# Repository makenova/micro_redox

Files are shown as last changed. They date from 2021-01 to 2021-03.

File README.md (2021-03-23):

# micro_redox

A family of 40% choc keyboards(34 keys) inspired by the Microdox and Ferris keyboards. 

 - The **micro_redox_split** is a pro-micro powered reversible split that does not require diodes.
 - The **micro_redox_semi_spit** is an integrated mcu semi split with usb-c and a rotary encoder.

Both boards can use either hot-swap sockets or the switches can be soldered directly to the pcb.

## Inspiration and differences

The Microdox(36 key MX spaced split) from Boardsource is a great keyboard. It was my first choc board, and after trying out a few keymaps, I realized I didn't need the outer thumb keys. In my experience, those keys are difficult to reach and do not serve a purpose on the keymap I've settled on.   
The Ferris(34 key choc spaced split) is another great keyboard. I like the look of the Ferris but a couple things made it uncomfortable for me to use:

* the thumb cluster is too close to the alphas 
* the pinky stagger is aggressive 

For the micro_redox family, I have kept the column stagger from the Microdox, made it choc spaced, and removed the outter thumb keys. I have also kept the distance between the homing keys and the thumb keys because I find it comfortable. Finally, I rotated the innermost thumb key which means that only 1u keycaps will fit there.  
For the split, I've also used a reversible pro-micro footprint so that both of them can face the same way i.e. component side down. It's a cleaner look.

## Libraries

These libraries that help me move fast. I may not actually be using them in this project, but adding them to keyboard projects is a habit. The are all added as git submodules so make sure you pull them down after you pull the repo.  
My thanks to the authors for sharing.

- [Keebio-components](https://github.com/keebio/keebio-components)
  - [@keebio](https://github.com/keebio)
- [Keebio-parts.pretty](https://github.com/keebio/Keebio-Parts.pretty)
  - [@keebio](https://github.com/keebio)
- [keyswtiches.pretty](https://github.com/daprice/keyswitches.pretty)
  - [@daprice](https://github.com/daprice)
- [random-keyboard-parts.pretty](https://github.com/ai03-2725/random-keyboard-parts.pretty)
  - [@ai03-2725](https://github.com/ai03-2725)
- [https://github.com/foostan/kbd](https://github.com/foostan/kbd)
  - [@foostan](https://github.com/foostan)
- [Customizable Rotary Encoder Knob](https://www.thingiverse.com/thing:2797118)
  - [tsw](https://www.thingiverse.com/tsw/designs)

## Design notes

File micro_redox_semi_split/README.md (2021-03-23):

# micro_redox_semi_split
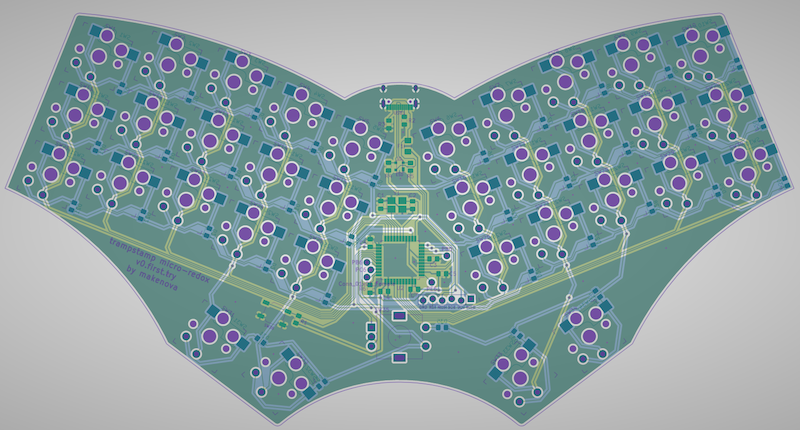
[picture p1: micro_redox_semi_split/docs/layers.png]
layers


### Features

- USB C
- integrated mcu
- rotary encoder
- choc spaced
- hot-swap or soldered

There are production files in the "gerbers" directory for the pcb and a skeleton case.
Simply upload the zip files to your PCB manufacturer of choice.

If you do not get this assembled by a factory you can find an interactive BOM in `bom` directory.

Starting firmware can be found on my QMK fork in the [`makenova`](https://github.com/makenova/qmk_firmware/tree/makenova/keyboards/makenova//micro_redox/semi_split) branch.

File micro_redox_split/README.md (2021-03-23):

# micro_redox_split
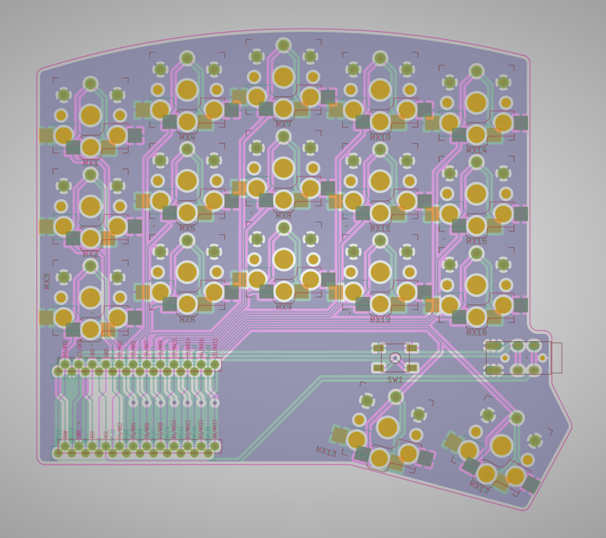
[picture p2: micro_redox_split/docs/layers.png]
layers


### Features

- diodeless
- reversible pcb
- reversible mcu
- choc spaced
- hot-swap or soldered

There are production files in the "gerbers" directory for the pcb and a skeleton case.
Just upload the zip files to your PCB manufacturer of choice.

You'll also need

* Pro Micro(PM) or compatible board
 * I prefer something with USB C
 * You can use a nice!nano if you want to make it wireless
* Headers for the PM
  * search for `Round Female Socket Pin Header`
* TRRS jack
* choc hot-swap sockets(optional)
* reset switch (optional)

Starting firmware can be found on my QMK fork in the [`makenova`](https://github.com/makenova/qmk_firmware/tree/makenova/keyboards/makenova//micro_redox/split) branch.

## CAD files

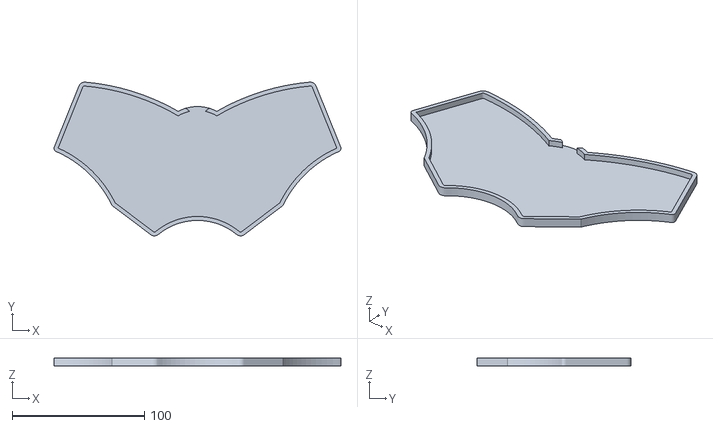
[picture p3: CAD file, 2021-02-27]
micro_redox_semi_split/docs/semi_split_slip_on.stl
217.1 x 116.3 x 6.00

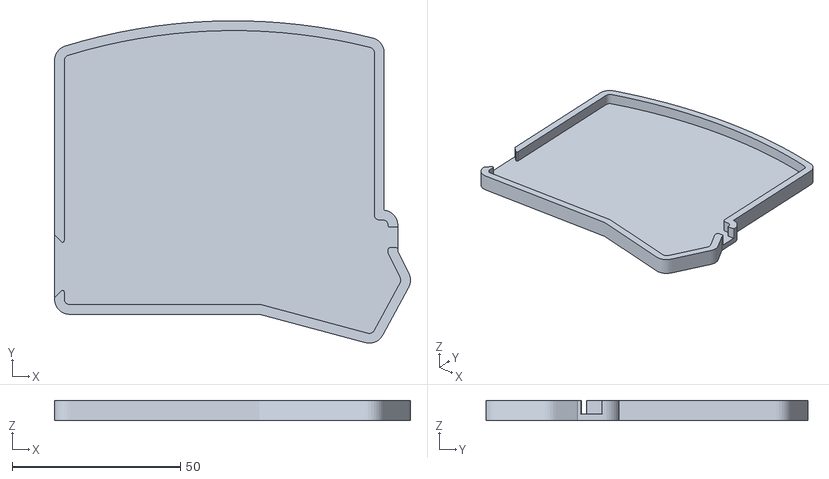
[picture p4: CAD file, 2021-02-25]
micro_redox_split/docs/slip-on.stl
105.9 x 95.9 x 6.00

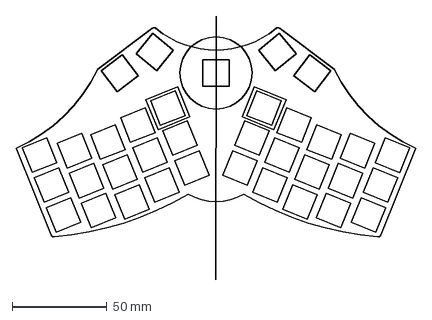
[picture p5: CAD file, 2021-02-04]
micro_redox_semi_split/docs/semi_split_plate_1_0.dxf
210.6 x 139.0 mm

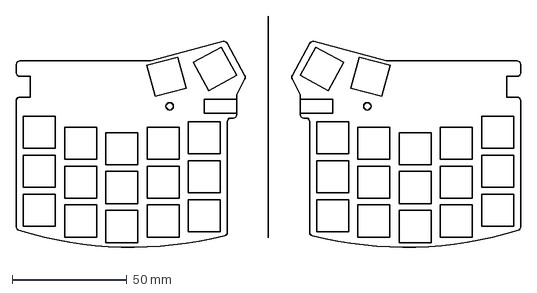
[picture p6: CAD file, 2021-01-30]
micro_redox_split/docs/plate_1_0.dxf
220.0 x 103.1 mm

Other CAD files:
HRO__TYPE-C-31-M-12.f3d

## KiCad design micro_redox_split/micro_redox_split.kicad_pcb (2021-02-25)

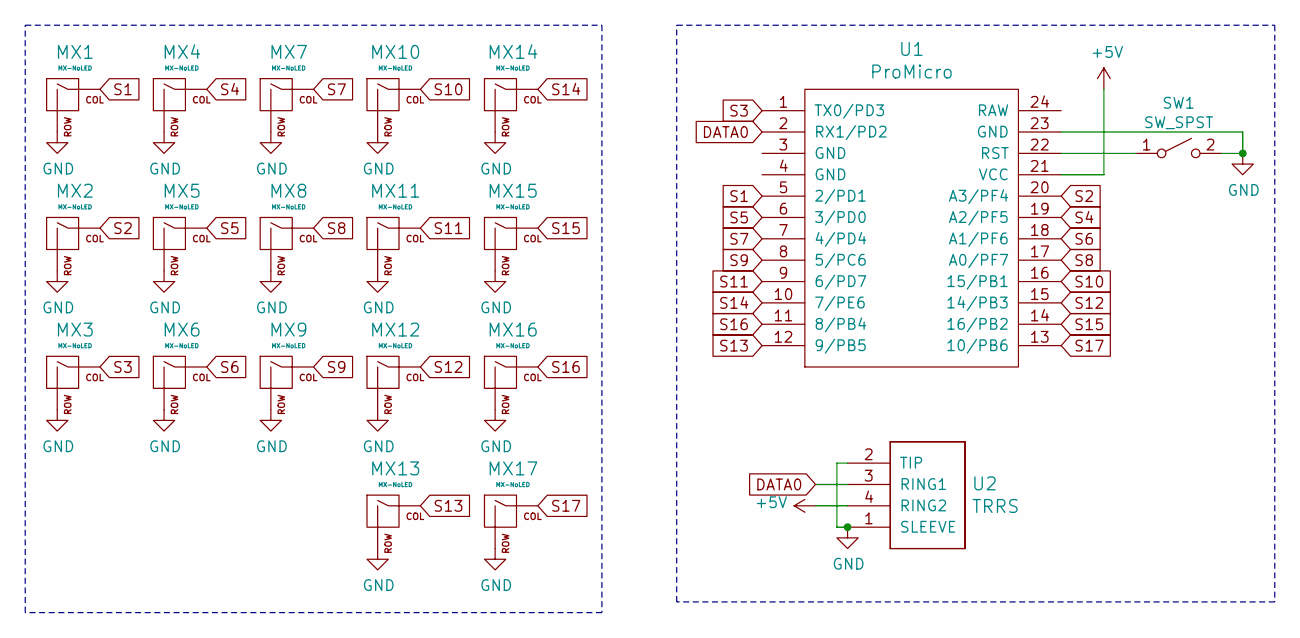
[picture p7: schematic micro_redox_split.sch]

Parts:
MX1, MX2, MX3, MX4, MX5, MX6, MX7, MX8, MX9, MX10, MX11, MX12, MX13, MX14, MX15, MX16, MX17: MX-NoLED; Kailh_socket_PG1350_optional_reversible
SW1: SW_SPST; SKQG-1155865-makenova-reversible
U1: ProMicro; ProMicro_v2-makenova-micro-redox
U2: TRRS; TRRS-PJ-320A-no-Fmask-makenova-reversible

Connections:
+5V: U1.21 (VCC), U2.4 (RING2)
DATA0: U1.2 (RX1/PD2), U2.3 (RING1)
GND: MX1.2 (ROW), MX2.2 (ROW), MX3.2 (ROW), MX4.2 (ROW), MX5.2 (ROW), MX6.2 (ROW), MX7.2 (ROW), MX8.2 (ROW), MX9.2 (ROW), MX10.2 (ROW), MX11.2 (ROW), MX12.2 (ROW), MX13.2 (ROW), MX14.2 (ROW), MX15.2 (ROW), MX16.2 (ROW), MX17.2 (ROW), SW1.2 (B), U1.23 (GND), U2.1 (SLEEVE), U2.2 (TIP)
unnamed: SW1.1 (A), U1.22 (RST)
S1: MX1.1 (COL), U1.5 (2/PD1)
S2: MX2.1 (COL), U1.20 (A3/PF4)
S3: MX3.1 (COL), U1.1 (TX0/PD3)
S4: MX4.1 (COL), U1.19 (A2/PF5)
S5: MX5.1 (COL), U1.6 (3/PD0)
S6: MX6.1 (COL), U1.18 (A1/PF6)
S7: MX7.1 (COL), U1.7 (4/PD4)
S8: MX8.1 (COL), U1.17 (A0/PF7)
S9: MX9.1 (COL), U1.8 (5/PC6)
S10: MX10.1 (COL), U1.16 (15/PB1)
S11: MX11.1 (COL), U1.9 (6/PD7)
S12: MX12.1 (COL), U1.15 (14/PB3)
S13: MX13.1 (COL), U1.12 (9/PB5)
S14: MX14.1 (COL), U1.10 (7/PE6)
S15: MX15.1 (COL), U1.14 (16/PB2)
S16: MX16.1 (COL), U1.11 (8/PB4)
S17: MX17.1 (COL), U1.13 (10/PB6)

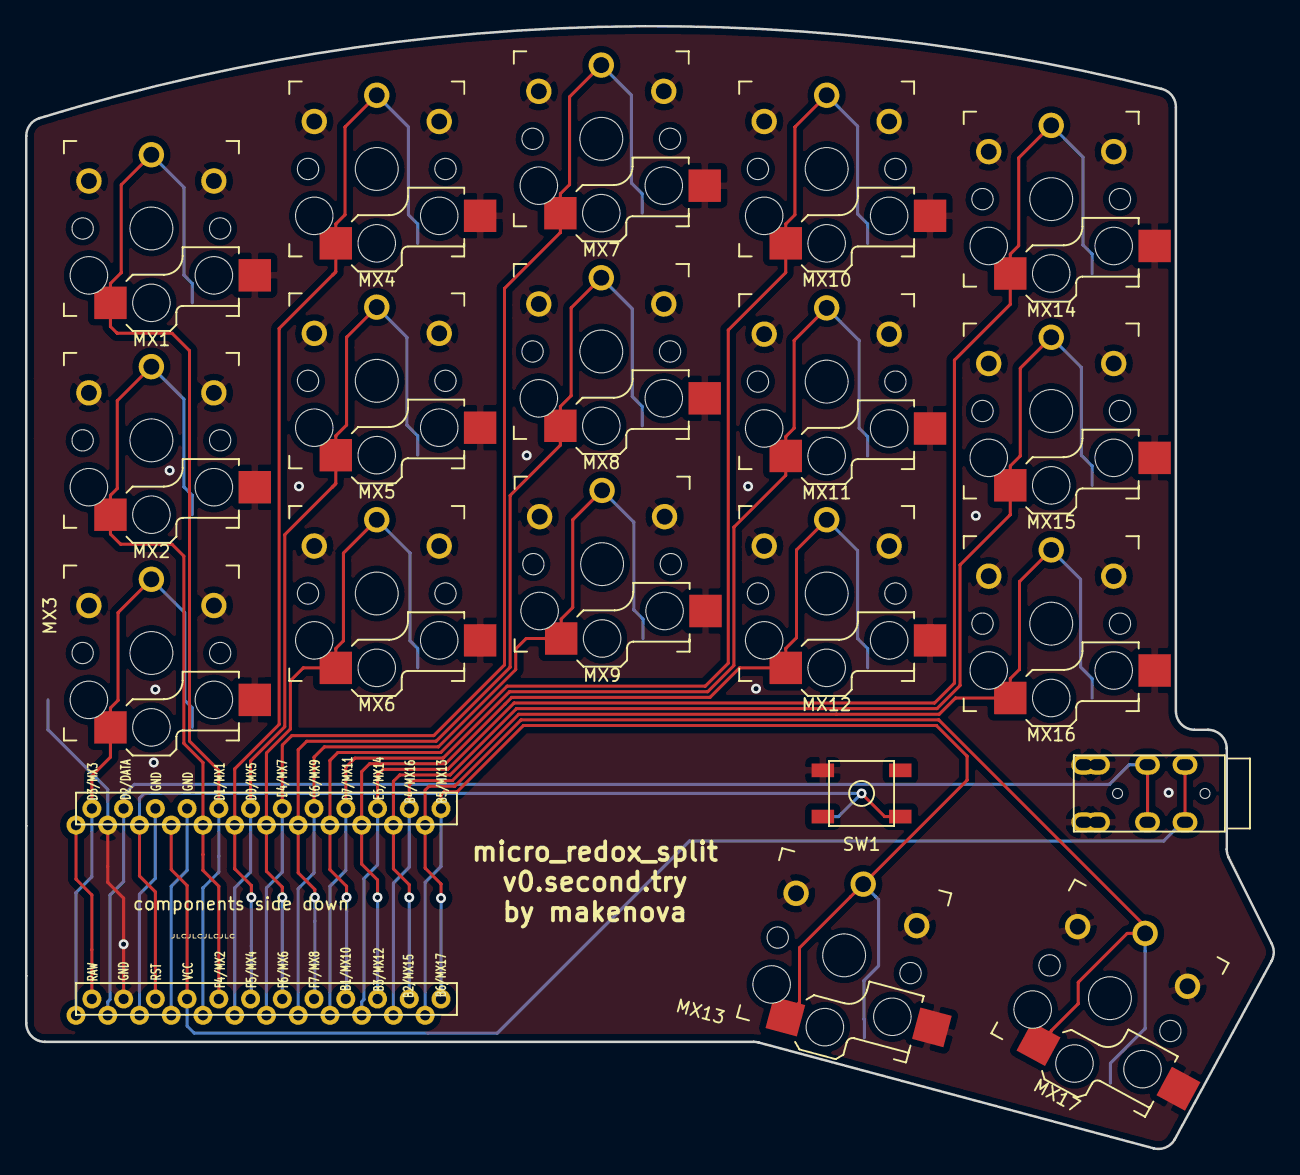
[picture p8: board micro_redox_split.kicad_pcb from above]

Board: 2 copper layers, 99.8 x 89.8 mm, 20 parts (1 on the bottom side), 21 nets.

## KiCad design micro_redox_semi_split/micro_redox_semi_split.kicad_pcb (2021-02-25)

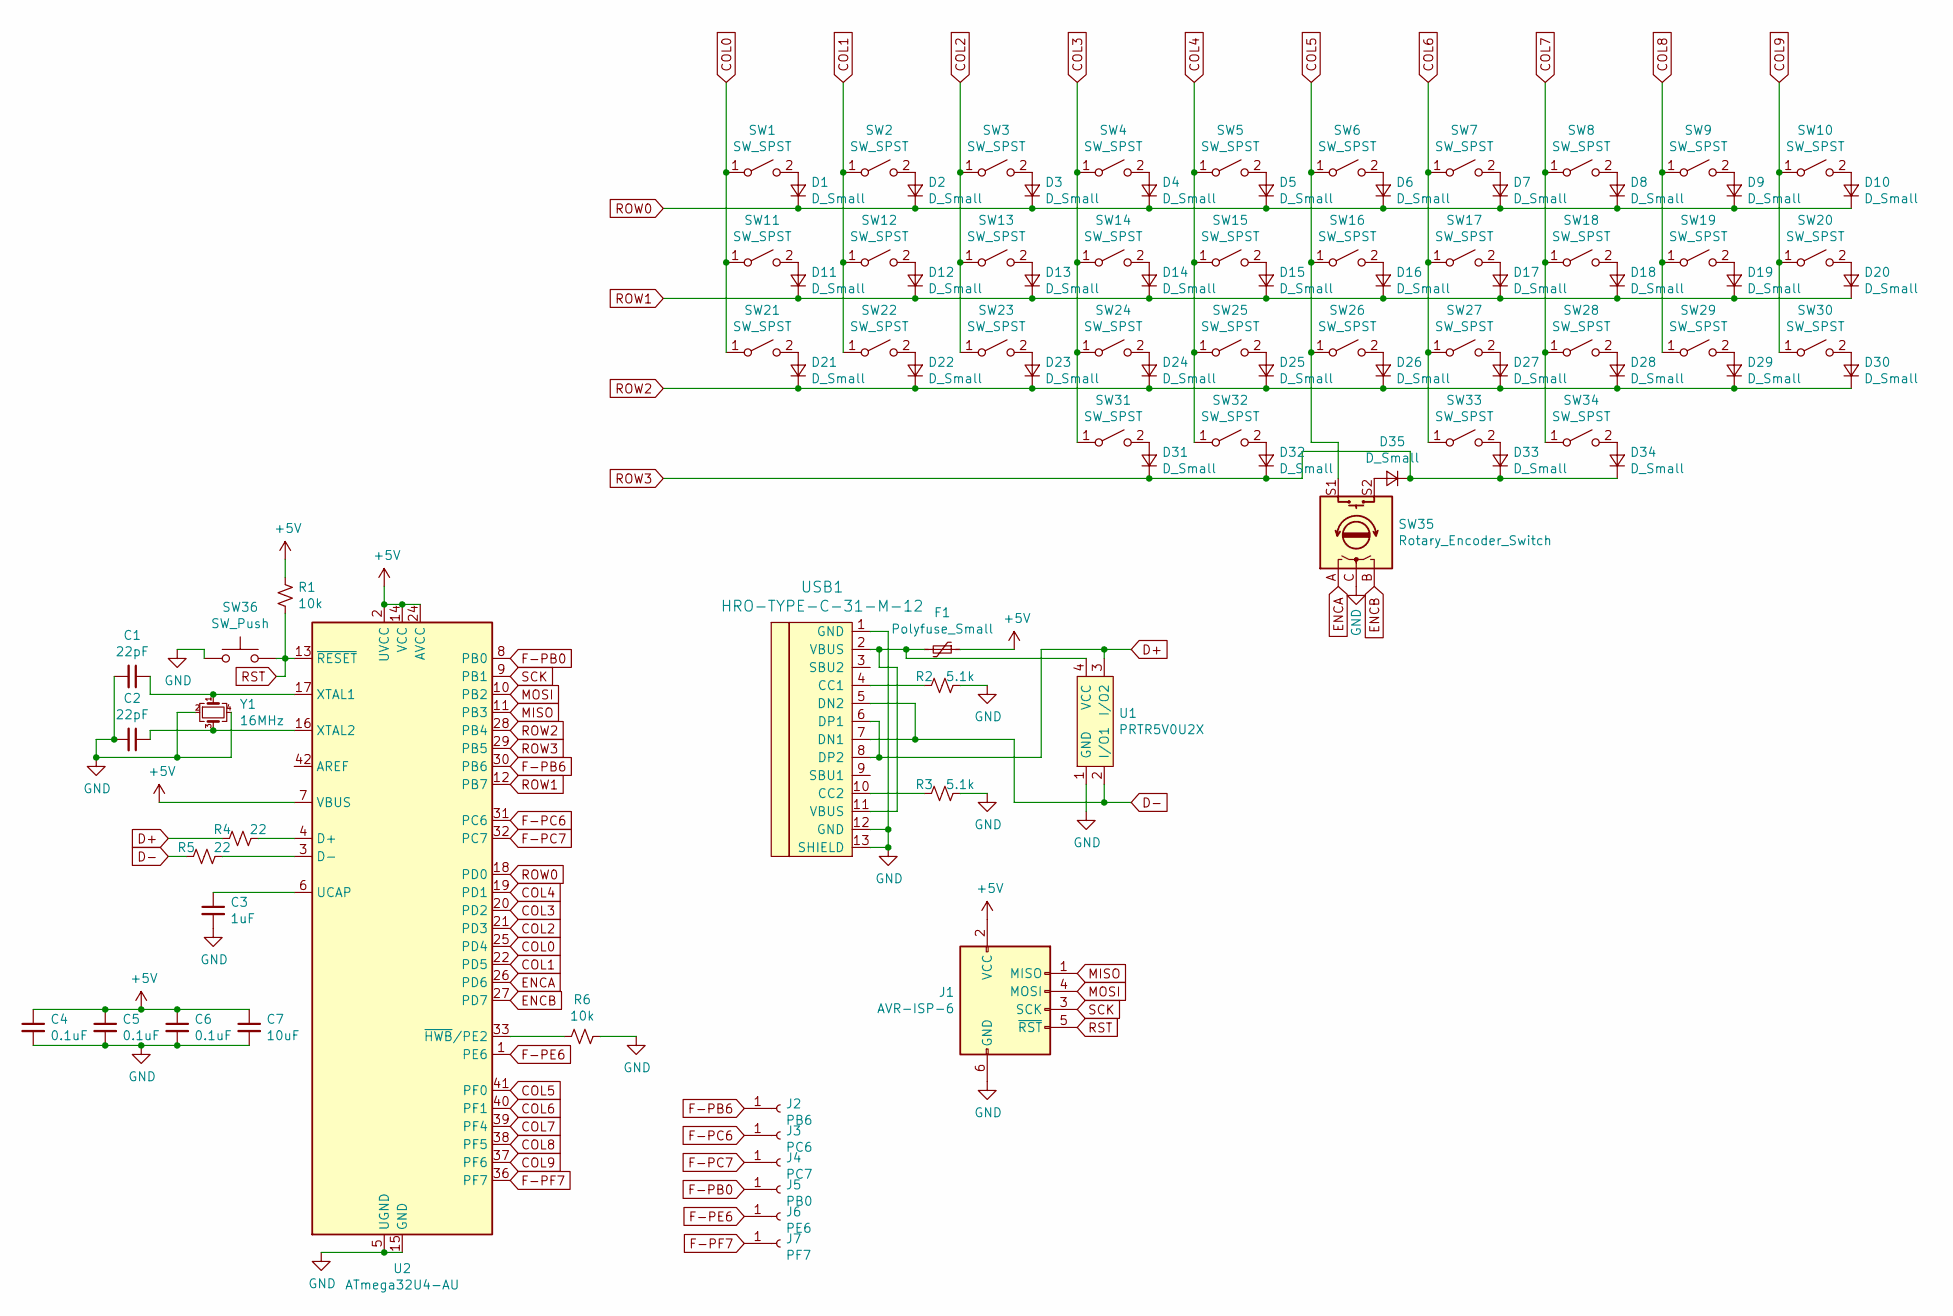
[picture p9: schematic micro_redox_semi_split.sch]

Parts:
C1, C2: 22pF; C_0805_2012Metric_Pad1.15x1.40mm_HandSolder
C3: 1uF; C_0805_2012Metric_Pad1.15x1.40mm_HandSolder
C4, C5, C6: 0.1uF; C_0805_2012Metric_Pad1.15x1.40mm_HandSolder
C7: 10uF; C_0805_2012Metric_Pad1.15x1.40mm_HandSolder
D1, D2, D3, D4, D5, D6, D7, D8, D9, D10, D11, D12, D13, D14, D15, D16, D17, D18, D19, D20, D21, D22, D23, D24, D25, D26, D27, D28, D29, D30, D31, D32, D33, D34, D35: D_Small; D_SOD-123
F1: Polyfuse_Small; Fuse_1206_3216Metric_Pad1.42x1.75mm_HandSolder
J1: AVR-ISP-6; ICSP-Header-ZigZag
J2: PB6; SinglePad
J3: PC6; SinglePad
J4: PC7; SinglePad
J5: PB0; SinglePad
J6: PE6; SinglePad
J7: PF7; SinglePad
R1, R6: 10k; R_0805_2012Metric_Pad1.15x1.40mm_HandSolder
R2, R3: 5.1k; R_0805_2012Metric_Pad1.15x1.40mm_HandSolder
R4, R5: 22; R_0805_2012Metric_Pad1.15x1.40mm_HandSolder
SW1, SW2, SW3, SW4, SW5, SW6, SW7, SW8, SW9, SW10, SW11, SW12, SW13, SW14, SW15, SW16, SW17, SW18, SW19, SW20, SW21, SW22, SW23, SW24, SW25, SW26, SW27, SW28, SW29, SW30, SW31, SW32, SW33, SW34: SW_SPST; Kailh_socket_PG1350_optional
SW35: Rotary_Encoder_Switch; RotaryEncoder_Alps_EC11E-Switch_Vertical_H20mm
SW36: SW_Push; SW_SPST_TL3342
U1: PRTR5V0U2X; SOT-143B
U2: ATmega32U4-AU; TQFP-44_10x10mm_P0.8mm
USB1: HRO-TYPE-C-31-M-12; HRO-TYPE-C-31-M-12-Assembly
Y1: 16MHz; Crystal_SMD_3225-4Pin_3.2x2.5mm_HandSoldering

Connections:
+5V: C4.1, C5.1, C6.1, C7.1, F1.1, J1.2 (VCC), R1.2, U2.2 (UVCC), U2.7 (VBUS), U2.14 (VCC), U2.24 (AVCC), U2.34 (VCC), U2.44 (AVCC)
COL0: SW1.1 (A), SW11.1 (A), SW21.1 (A), U2.25 (PD4)
COL1: SW2.1 (A), SW12.1 (A), SW22.1 (A), U2.22 (PD5)
COL2: SW3.1 (A), SW13.1 (A), SW23.1 (A), U2.21 (PD3)
COL3: SW4.1 (A), SW14.1 (A), SW24.1 (A), SW31.1 (A), U2.20 (PD2)
COL4: SW5.1 (A), SW15.1 (A), SW25.1 (A), SW32.1 (A), U2.19 (PD1)
COL5: SW6.1 (A), SW16.1 (A), SW26.1 (A), SW35.S1, U2.41 (PF0)
COL6: SW7.1 (A), SW17.1 (A), SW27.1 (A), SW33.1 (A), U2.40 (PF1)
COL7: SW8.1 (A), SW18.1 (A), SW28.1 (A), SW34.1 (A), U2.39 (PF4)
COL8: SW9.1 (A), SW19.1 (A), SW29.1 (A), U2.38 (PF5)
COL9: SW10.1 (A), SW20.1 (A), SW30.1 (A), U2.37 (PF6)
D+: R4.2, U1.3 (I/O2), USB1.6 (DP1), USB1.8 (DP2)
D-: R5.1, U1.2 (I/O1), USB1.5 (DN2), USB1.7 (DN1)
ENCA: SW35.A, U2.26 (PD6)
ENCB: SW35.B, U2.27 (PD7)
F-PB0: J5.1, U2.8 (PB0)
F-PB6: J2.1, U2.30 (PB6)
F-PC6: J3.1, U2.31 (PC6)
F-PC7: J4.1, U2.32 (PC7)
F-PE6: J6.1, U2.1 (PE6)
F-PF7: J7.1, U2.36 (PF7)
GND: C1.2, C2.2, C3.2, C4.2, C5.2, C6.2, C7.2, J1.6 (GND), R2.1, R3.1, R6.1, SW35.C, SW36.1, U1.1 (GND), U2.5 (UGND), U2.15 (GND), U2.23 (GND), U2.35 (GND), U2.43 (GND), USB1.1 (GND), USB1.12 (GND), USB1.13 (SHIELD), Y1.2, Y1.4
MISO: J1.1 (MISO), U2.11 (PB3)
MOSI: J1.4 (MOSI), U2.10 (PB2)
unnamed: C1.1, U2.17 (XTAL1), Y1.1
unnamed: C2.1, U2.16 (XTAL2), Y1.3
unnamed: C3.1, U2.6 (UCAP)
unnamed: D1.2 (A), SW1.2 (B)
unnamed: D2.2 (A), SW2.2 (B)
unnamed: D3.2 (A), SW3.2 (B)
unnamed: D4.2 (A), SW4.2 (B)
unnamed: D5.2 (A), SW5.2 (B)
unnamed: D6.2 (A), SW6.2 (B)
unnamed: D7.2 (A), SW7.2 (B)
unnamed: D8.2 (A), SW8.2 (B)
unnamed: D9.2 (A), SW9.2 (B)
unnamed: D10.2 (A), SW10.2 (B)
unnamed: D11.2 (A), SW11.2 (B)
unnamed: D12.2 (A), SW12.2 (B)
unnamed: D13.2 (A), SW13.2 (B)
unnamed: D14.2 (A), SW14.2 (B)
unnamed: D15.2 (A), SW15.2 (B)
unnamed: D16.2 (A), SW16.2 (B)
unnamed: D17.2 (A), SW17.2 (B)
unnamed: D18.2 (A), SW18.2 (B)
unnamed: D19.2 (A), SW19.2 (B)
unnamed: D20.2 (A), SW20.2 (B)
unnamed: D21.2 (A), SW21.2 (B)
unnamed: D22.2 (A), SW22.2 (B)
unnamed: D23.2 (A), SW23.2 (B)
unnamed: D24.2 (A), SW24.2 (B)
unnamed: D25.2 (A), SW25.2 (B)
unnamed: D26.2 (A), SW26.2 (B)
unnamed: D27.2 (A), SW27.2 (B)
unnamed: D28.2 (A), SW28.2 (B)
unnamed: D29.2 (A), SW29.2 (B)
unnamed: D30.2 (A), SW30.2 (B)
unnamed: D31.2 (A), SW31.2 (B)
unnamed: D32.2 (A), SW32.2 (B)
unnamed: D33.2 (A), SW33.2 (B)
unnamed: D34.2 (A), SW34.2 (B)
unnamed: D35.2 (A), SW35.S2
unnamed: F1.2, U1.4 (VCC), USB1.2 (VBUS), USB1.11 (VBUS)
unnamed: R2.2, USB1.4 (CC1)
unnamed: R3.2, USB1.10 (CC2)
unnamed: R4.1, U2.4 (D+)
unnamed: R5.2, U2.3 (D-)
unnamed: R6.2, U2.33 (~HWB~/PE2)
ROW0: D1.1 (K), D2.1 (K), D3.1 (K), D4.1 (K), D5.1 (K), D6.1 (K), D7.1 (K), D8.1 (K), D9.1 (K), D10.1 (K), U2.18 (PD0)
ROW1: D11.1 (K), D12.1 (K), D13.1 (K), D14.1 (K), D15.1 (K), D16.1 (K), D17.1 (K), D18.1 (K), D19.1 (K), D20.1 (K), U2.12 (PB7)
ROW2: D21.1 (K), D22.1 (K), D23.1 (K), D24.1 (K), D25.1 (K), D26.1 (K), D27.1 (K), D28.1 (K), D29.1 (K), D30.1 (K), U2.28 (PB4)
ROW3: D31.1 (K), D32.1 (K), D33.1 (K), D34.1 (K), D35.1 (K), U2.29 (PB5)
RST: J1.5 (~RST), R1.1, SW36.2, U2.13 (~RESET)
SCK: J1.3 (SCK), U2.9 (PB1)

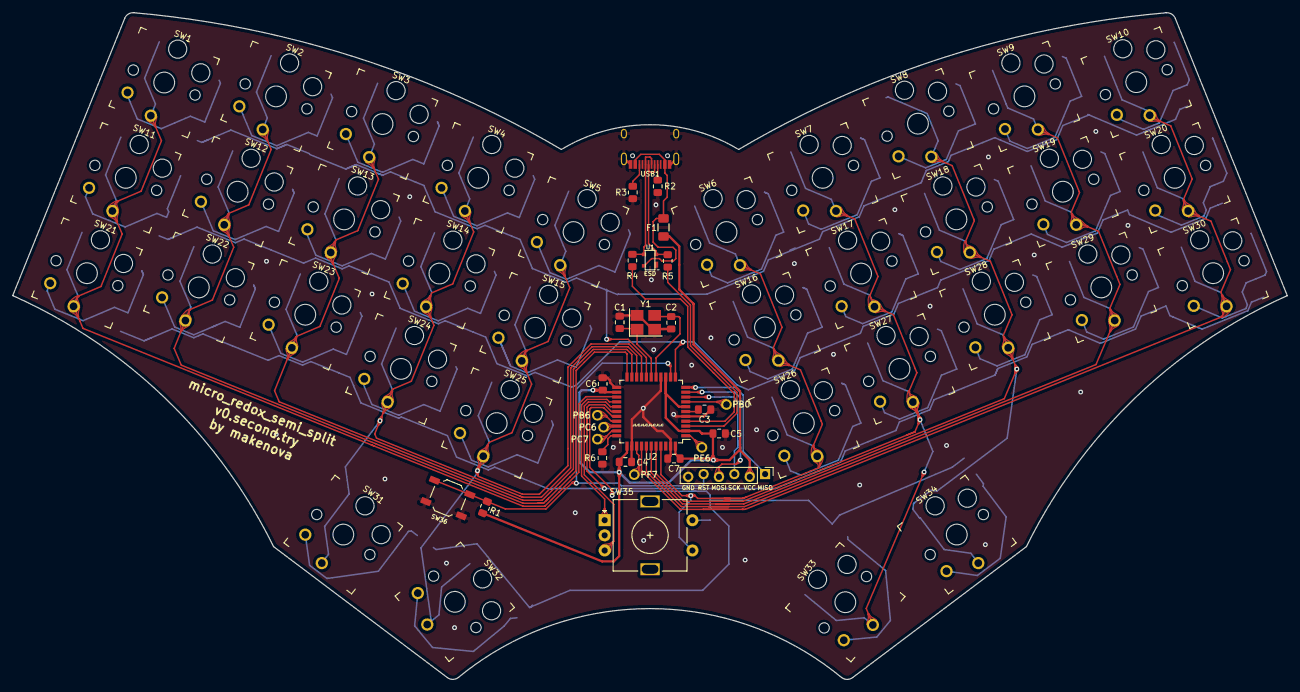
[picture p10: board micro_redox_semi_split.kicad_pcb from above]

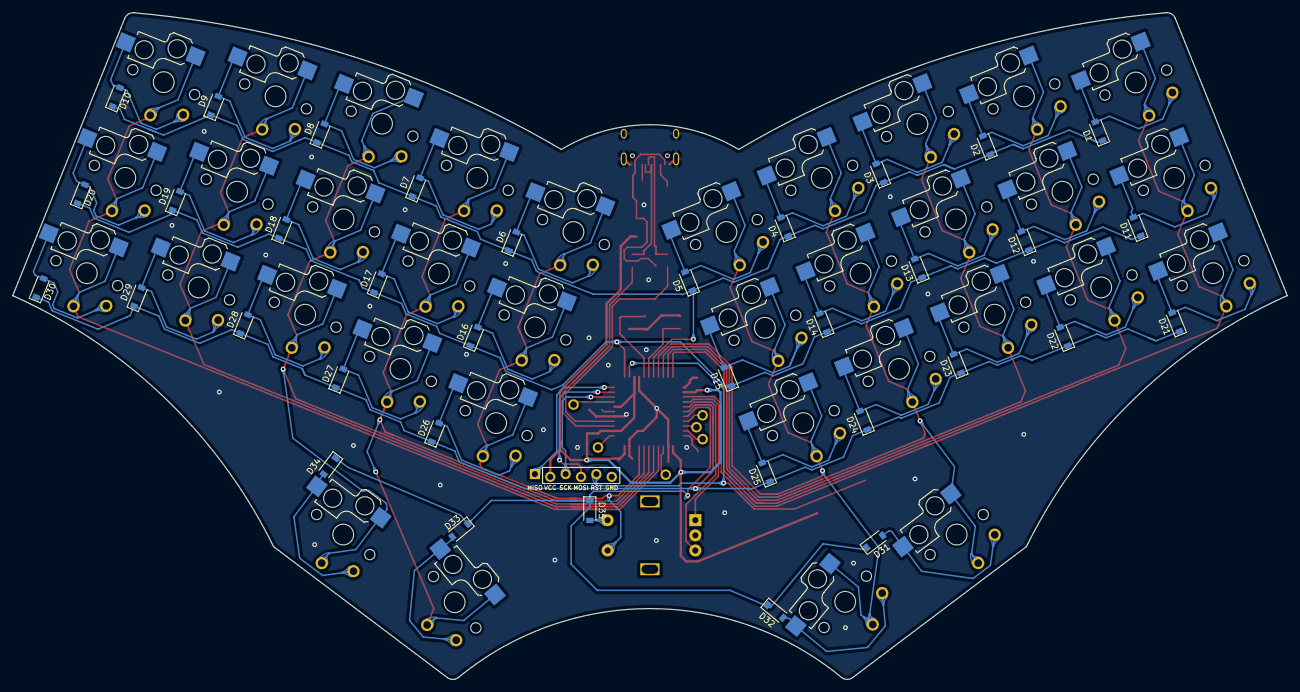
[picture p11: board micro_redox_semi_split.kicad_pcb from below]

Board: 2 copper layers, 210.6 x 110.1 mm, 96 parts (35 on the bottom side), 74 nets.

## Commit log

2021-01-30 make it so
    [HRO__TYPE-C-31-M-12.f3d, microdox_case_v0.1.stl, microdox_high_case_v0.1.stl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]
2021-02-04 add semi split
    [micro_redox_semi_split-B_Cu.gbr, micro_redox_semi_split-B_Mask.gbr, micro_redox_semi_split-B_Paste.gbr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]
2021-02-07 touch up and try some plugins
    [micro_redox_semi_split.kicad_pcb, micro_redox_semi_split_rounded.kicad_pcb]
2021-02-25 fixes for protos
    [micro_redox_semi_split-B_Cu.gbr, micro_redox_semi_split-B_Mask.gbr, micro_redox_semi_split-B_Paste.gbr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]
2021-02-27 add slip-on case
    [semi_split_slip_on.stl]
2021-03-23 more stuff
    [micro_redox_semi_split_rounded.kicad_pcb]
